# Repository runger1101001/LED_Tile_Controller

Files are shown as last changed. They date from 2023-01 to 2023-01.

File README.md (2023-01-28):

# Trixel Controller v1.0 Hardware

ESP32-C3 based controller board for trixel tiles.

Firmware for it can be found [here](https://github.com/runger1101001/led_driver_esp32).

More detailed explanation of how to use this controller can be found in the firmware documentation as well as the documentation for [the web ui](https://github.com/runger1101001/trixelcontroller-ui).

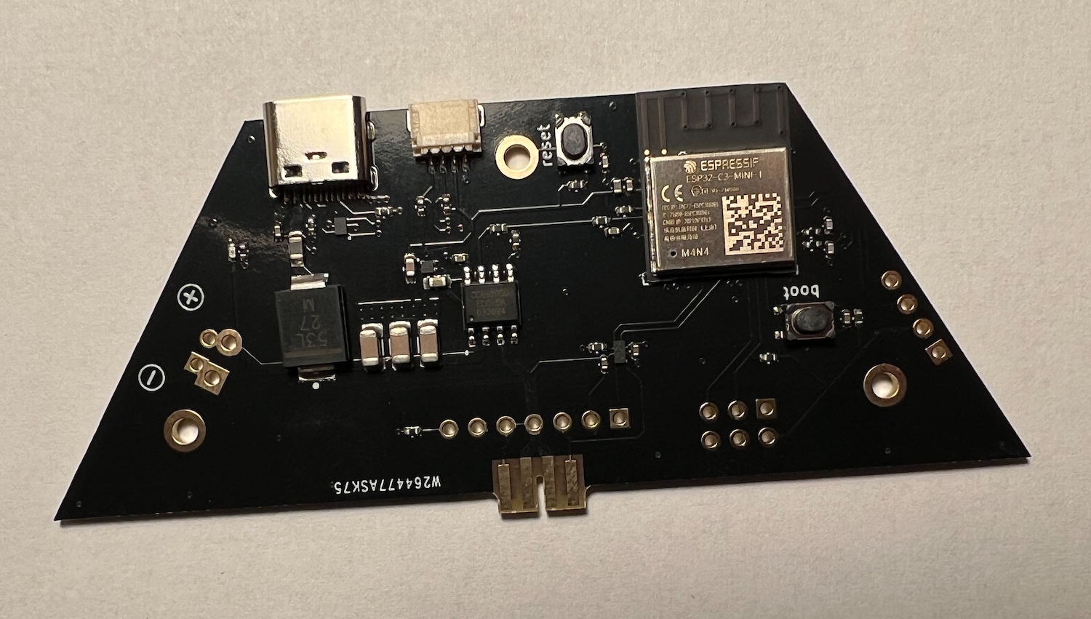
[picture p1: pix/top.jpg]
Top View


## Features

- ESP32-C3-MINI MCU
- 1 Trixel connector for board to board connections and as 1x7 header
- USB-C for power, serial debugging and programming
- Stemma/QT compatible I2C port
- Current sensing via hall effect current sensor
- Current levels up to 3A supported via USB, up to 5A via power header
- Buttons for Boot and Reset (not really needed with USB)
- Serial RX/TX routed to header for serial programming (don't know why since you have USB)
- 6 additional IOs routed to 2x3 header
- 5V power input header

## Using this project

This project was created in KiCad 6. You may need symbols/footprints from [my KiCad library](https://github.com/runger1101001/kicad-lib-runger).

Ordering the controller board PCB should not be difficult. It is a fairly simple 4 layer board. The board outline requires routing. 

Pay attention to the slot in the board to board connector (gerber layer User.1), which has to be routed out precisely for the connector to fit and work. The board thickness should be 1.6mm, other thicknesses will not work with the connector.

## Flashing the controller

To flash firmware to the controller, connect to USB via it's USB-C port. You can then program it with the usual software (ArduinoIDE, PlatformIO, etc). When configuring the software, you can treat it as a ESP32-C3-DevKit.

See the [trixel controller firmware](https://github.com/runger1101001/led_driver_esp32) for a working example using PlatformIO.

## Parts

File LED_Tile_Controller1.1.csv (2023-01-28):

Item | Ref Des | Qty | Manufacturer | Mfg Part # | Description / Value | Package | Type | Your Instructions / Notes
1 | C1,C2,C3 | 3 | Murata | GRM31CR61A476ME15K | 47uF 10V | C_1206_3216Metric | SMD | ; Unpolarized capacitor;
2 | C4,C7,C11,C14,C17,C18 | 6 | Murata | GRM155R71A104KA01J | 100nF 10V | C_0402_1005Metric | SMD | ; Unpolarized capacitor;
3 | C6 | 1 | Murata | ZRB15XR61A106ME01D | 10uF 10V | C_0402_1005Metric | SMD | ; Unpolarized capacitor;
4 | C8,C10 | 2 | Vishay | VJ0402A470GXQCW1BC | 47pF 10V | C_0402_1005Metric | SMD | ; Unpolarized capacitor;
5 | C12,C15 | 2 | Taiyo Yuden | EMK107ABJ225KA8T | 2.2uF 16V | C_0603_1608Metric | SMD | ; Unpolarized capacitor;
6 | C13 | 1 | Murata | GRT155C80J105KE01D | 1uF 6.3V | C_0402_1005Metric | SMD | ; Unpolarized capacitor;
7 | C16 | 1 | Taiyo Yuden | LMF105B7103KVHF | 10nF 10V | C_0402_1005Metric | SMD | ; Unpolarized capacitor;
8 | D2 | 1 | Vishay | SSC53L-M3/57T | SSC53L-M3/57T | D_SMC | SMD | ; Diode;
9 | D3 | 1 | Wurth | 150040VS73240 | green | LED_0402_1005Metric | SMD | ; Light emitting diode;
10 | FB1 | 1 | Laird | HI0805P390R-10 | 40Ω@100Mhz | L_0805_2012Metric | SMD | ; Ferrite bead;
11 | J5 | 1 | HRO | HRO_TYPE-C-31-M-12 | USB_C_Receptacle_USB2.0 | USB_C_Receptacle_HRO_TYPE-C-31-M-12 | SMD | ; USB 2.0-only Type-C Receptacle connector; https://www.usb.org/sites/default/files/documents/usb_type-c.zip
12 | J6 | 1 | JST | SH_SM04B-SRSS-TB | Stemma/QT | JST_SH_SM04B-SRSS-TB_1x04-1MP_P1.00mm_Horizontal | SMD | ; Generic connectable mounting pin connector, single row, 01x04, script generated (kicad-library-utils/schlib/autogen/connector/);
13 | R1,R3,R6,R7,R14,R16 | 6 | Generic | Generic 1% | 10k | R_0402_1005Metric | SMD | ; Resistor;
14 | R2,R8,R9,R10,R13 | 5 | Generic | Generic | 5k1 | R_0402_1005Metric | SMD | ; Resistor;
15 | R4,R5 | 2 | Generic | Generic | 27R | R_0402_1005Metric | SMD | ; Resistor;
16 | R11 | 1 | Generic | Generic | 330R | R_0402_1005Metric | SMD | ; Resistor;
17 | R12 | 1 | Generic | Generic | 2k2 | R_0402_1005Metric | SMD | ; Resistor;
18 | R15 | 1 | Generic | Generic 1% | 20k | R_0402_1005Metric | SMD | ; Resistor;
19 | SW1,SW2 | 2 | C&K | PTS810 SJS 250 SMTR LFS | SW_Push | PTS_810 | SMD | ; Push button switch, generic, two pins;
20 | U2 | 1 | Espressif | ESP32-C3-MINI-1-N4 | ESP32-C3-MINI-1 | ESP32-C3-MINI-1 | SMD | ; ESP32-C3-MINI-1 is a general-purpose Wi-Fi and Bluetooth LE module. This module features a rich set of peripherals and a small size, which makes it an ideal choice for smart home, industrial automation, health care, consumer electronics, etc; https://www.espressif.com/sites/default/files/documentation/esp32-c3-mini-1_datasheet_en.pdf
21 | U3 | 1 | Crosschip | CC6900SO-5A | CC6900SO-5A | SOIC-8_3.9x4.9mm_P1.27mm | SMD | ; ±20A Bidirectional Hall-Effect Current Sensor, +3.3V supply, 66mV/A, SOIC-8; http://www.allegromicro.com/~/media/Files/Datasheets/ACS725-Datasheet.ashx?la=en
22 | U4 | 1 | Micrel / Microchip | MIC5524-3.3YMT-T5 | MIC5524-3.3YMT-T5 | TDFN-4-1EP_1x1mm_P0.65mm_EP0.5x0.5mm | SMD | ; 500mA low dropout LDO, Fixed or Adjustable, 1x1mm Thin-DFN; https://www.mouser.at/datasheet/2/268/MIC5524-875860.pdf
23 | U5 | 1 | Nexperia | PRTR5V0U2F | PRTR5V0U2F | SOT-886 | SMD | ; Very low capacitance ESD protection diode, 2 data-line, SOT-666; https://www.st.com/resource/en/datasheet/usblc6-2.pdf
24 | U6 | 1 | NXP | NXB0102GTX | NXB0102GTX | SOT833-1 (XSON8) | SMD | ; Dual supply translating transceiver; auto direction sensing; 3-state; https://www.mouser.at/datasheet/2/916/NXB0102-1714053.pdf

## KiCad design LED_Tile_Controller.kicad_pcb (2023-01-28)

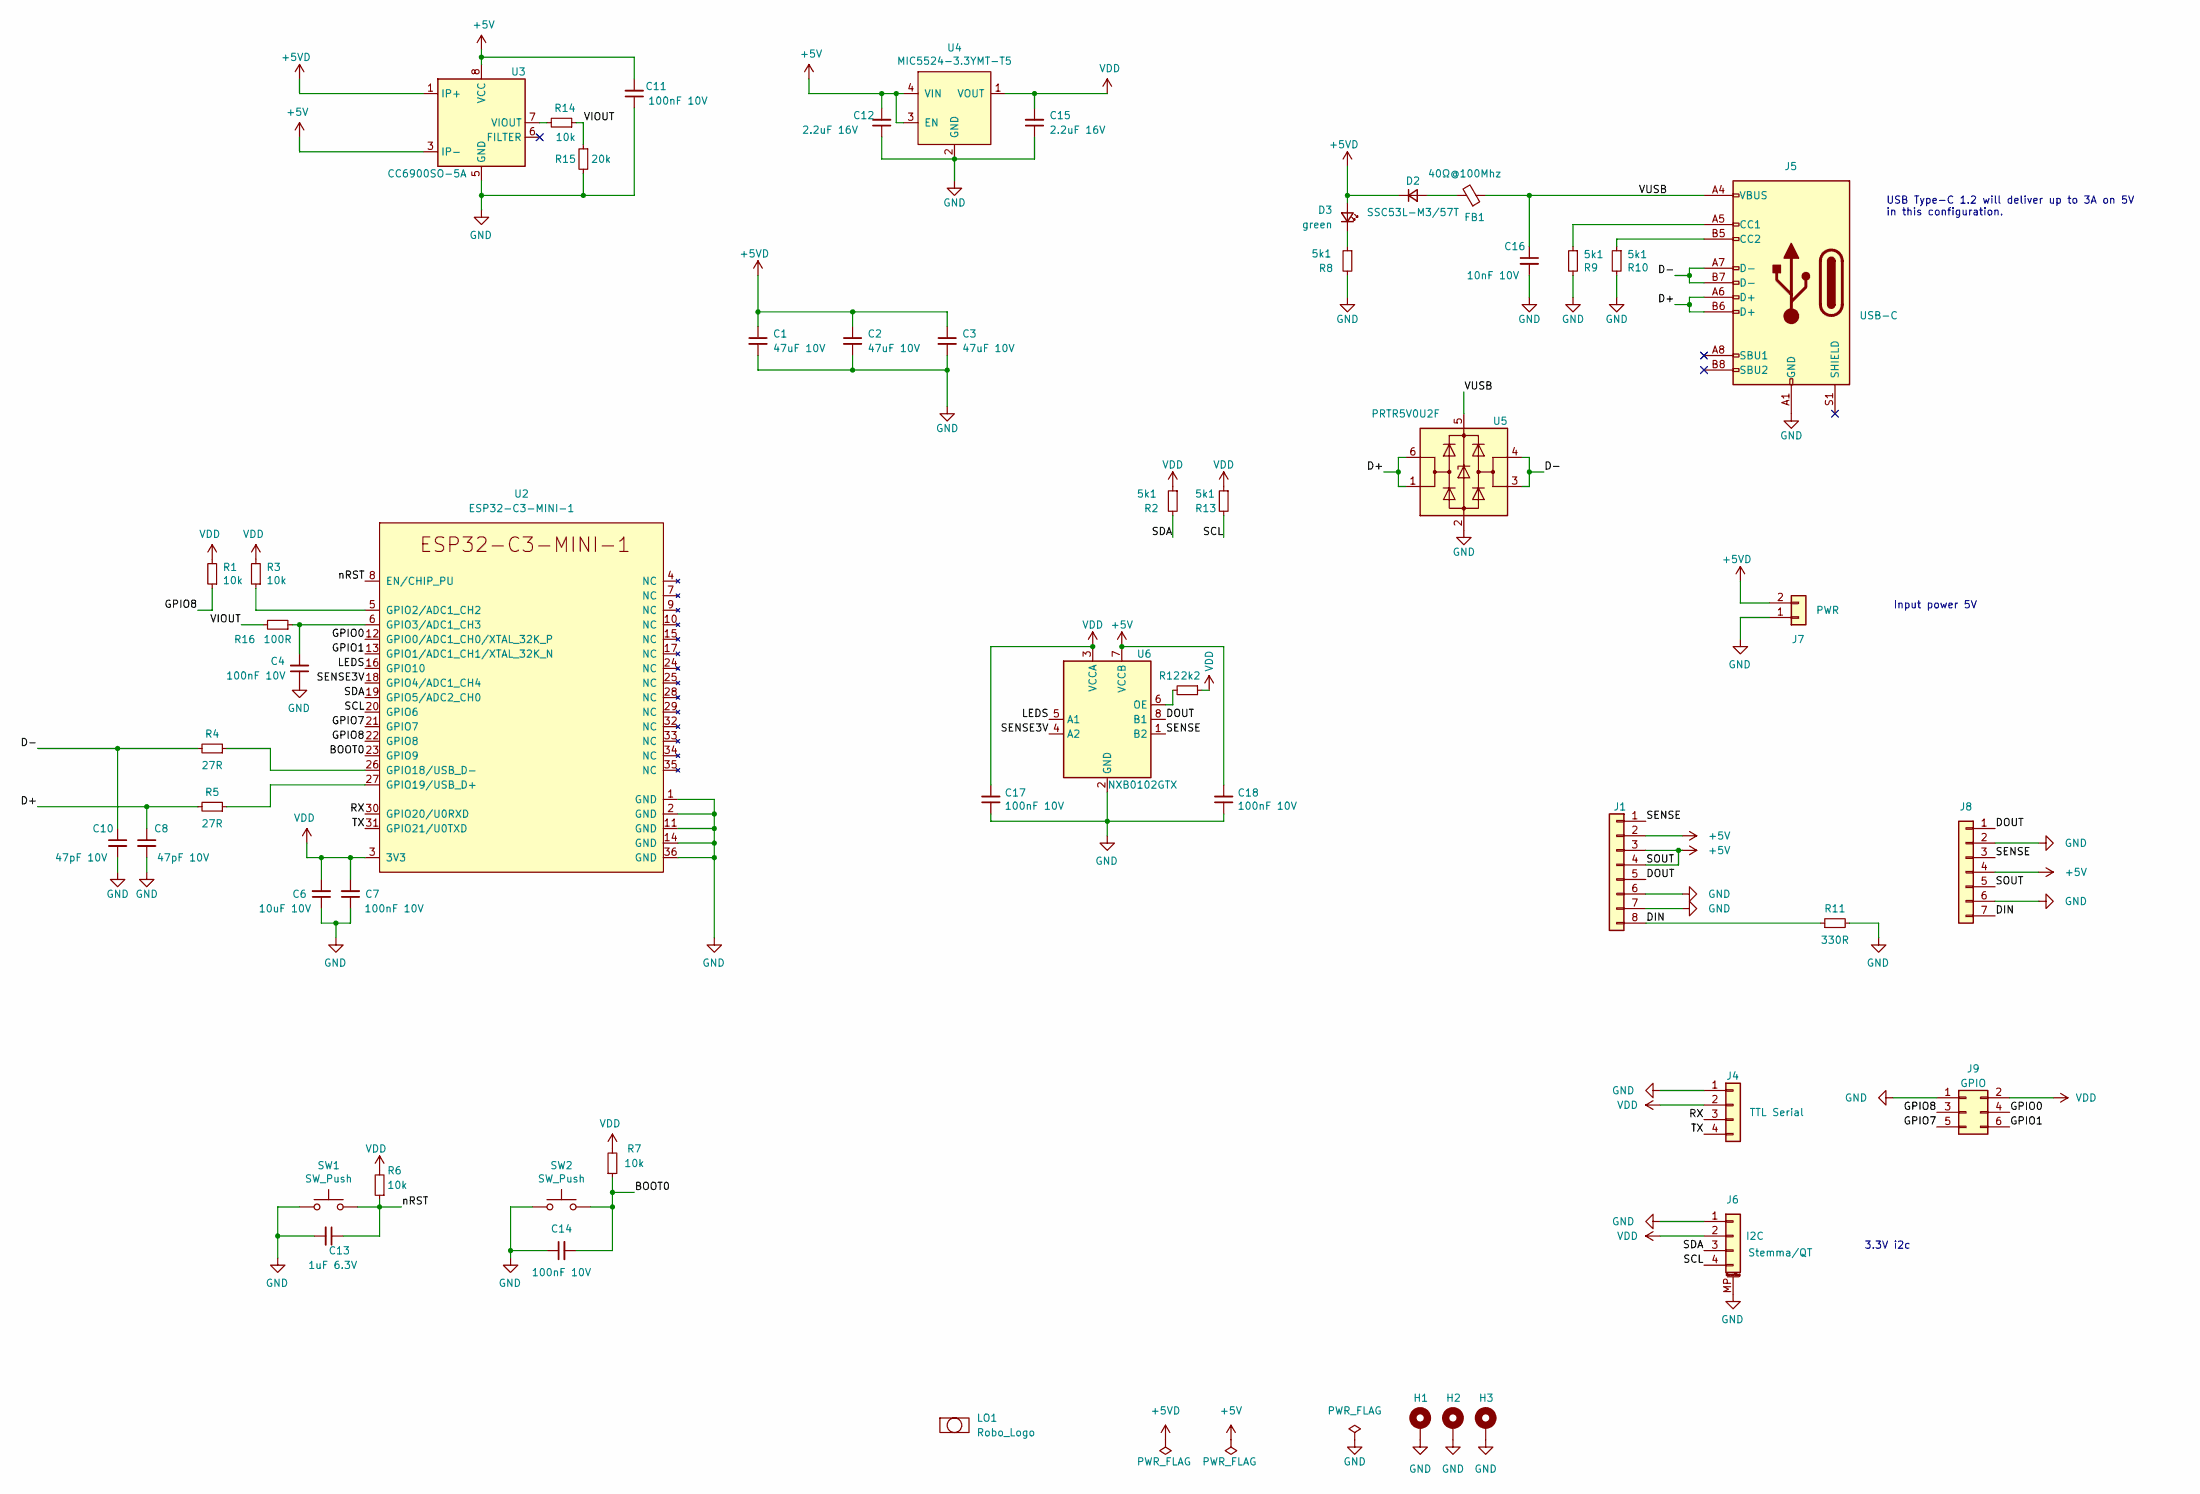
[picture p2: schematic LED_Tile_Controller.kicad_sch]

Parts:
C1, C2, C3: 47uF 10V; C_1206_3216Metric; Part GRM31CR61A476ME15K
C4, C7, C11, C14, C17, C18: 100nF 10V; C_0402_1005Metric; Part GRM155R71A104KA01J
C6: 10uF 10V; C_0402_1005Metric; Part ZRB15XR61A106ME01D
C8, C10: 47pF 10V; C_0402_1005Metric; Part VJ0402A470GXQCW1BC
C12, C15: 2.2uF 16V; C_0603_1608Metric; Part EMK107ABJ225KA8T
C13: 1uF 6.3V; C_0402_1005Metric; Part GRT155C80J105KE01D
C16: 10nF 10V; C_0402_1005Metric; Part LMF105B7103KVHF
D2: SSC53L-M3/57T; D_SMC; Part SSC53L-M3/57T
D3: green; LED_0402_1005Metric; Part 150040VS73240
FB1: 40Ω@100Mhz; L_0805_2012Metric; Part HI0805P390R-10
H1, H2, H3: MountingHole_Pad; MountingHole_2.2mm_M2_DIN965_Pad
J1: AVX 009159008061816; AVX_Edge_8; Part 009159008061816
J4: Conn_01x04; PinHeader_1x04_P2.54mm_Vertical
J5: USB_C_Receptacle_USB2.0; USB_C_Receptacle_HRO_TYPE-C-31-M-12; Part HRO_TYPE-C-31-M-12
J6: Stemma/QT; JST_SH_SM04B-SRSS-TB_1x04-1MP_P1.00mm_Horizontal; Part SH_SM04B-SRSS-TB
J7: Conn_01x02; Power_Combo
J8: Conn_01x07; PinHeader_1x07_P2.54mm_Horizontal
J9: Conn_02x03_Odd_Even; PinHeader_2x03_P2.54mm_Vertical
LO1: Robo_Logo; Robo_logo2
R1, R3, R6, R7: 10k; R_0402_1005Metric; Part Generic
R2, R13: 5k1; R_0402_1005Metric; Part Generic
R4, R5: 27R; R_0402_1005Metric; Part Generic
R8, R9, R10: 5k1; R_0402_1005Metric; Part Generic 1%
R11: 330R; R_0402_1005Metric; Part Generic
R12: 2k2; R_0402_1005Metric; Part Generic
R14: 10k; R_0402_1005Metric; Part Generic 1%
R15: 20k; R_0402_1005Metric; Part Generic 1%
R16: 100R; R_0402_1005Metric; Part Generic 1%
SW1, SW2: SW_Push; PTS_810; Part PTS810 SJS 250 SMTR LFS
U2: ESP32-C3-MINI-1; Part ESP32-C3-MINI-1-N4
U3: CC6900SO-5A; SOIC-8_3.9x4.9mm_P1.27mm; Part CC6900SO-5A
U4: MIC5524-3.3YMT-T5; TDFN-4-1EP_1x1mm_P0.65mm_EP0.5x0.5mm; Part MIC5524-3.3YMT-T5
U5: PRTR5V0U2F; SOT-886; Part PRTR5V0U2F
U6: NXB0102GTX; SOT833-1 (XSON8); Part NXB0102GTX

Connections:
+5V: C11.2, C12.2, C18.2, J1.2, J1.3, J1.4, J8.4, J8.5, U3.3 (IP-), U3.4 (IP-), U3.8 (VCC), U4.3 (EN), U4.4 (VIN), U6.7 (VCCB)
+5VD: C1.1, C2.1, C3.1, D2.1 (K), D3.2 (A), J7.2, U3.1 (IP+), U3.2 (IP+)
/BOOT0: C14.2, R7.1, SW2.2, U2.23 (GPIO9)
/D+: C8.1, J5.A6 (D+), J5.B6 (D+), R5.2, U5.1 (I/O1), U5.6 (I/O1)
/D-: C10.1, J5.A7 (D-), J5.B7 (D-), R4.2, U5.3 (I/O2), U5.4 (I/O2)
/DIN: J1.8, J8.7, R11.1
/DOUT: J1.5, J8.1, U6.8 (B1)
/GPIO0: J9.4, U2.12 (GPIO0/ADC1_CH0/XTAL_32K_P)
/GPIO1: J9.6, U2.13 (GPIO1/ADC1_CH1/XTAL_32K_N)
/GPIO7: J9.5, U2.21 (GPIO7)
/GPIO8: J9.3, R1.1, U2.22 (GPIO8)
/LEDS: U2.16 (GPIO10), U6.5 (A1)
/RX: J4.3, U2.30 (GPIO20/U0RXD)
/SCL: J6.4, R13.2, U2.20 (GPIO6)
/SDA: J6.3, R2.2, U2.19 (GPIO5/ADC2_CH0)
/SENSE: J1.1, J8.3, U6.1 (B2)
/SENSE3V: U2.18 (GPIO4/ADC1_CH4), U6.4 (A2)
/TX: J4.4, U2.31 (GPIO21/U0TXD)
/VIOUT: R14.1, R15.1, R16.2
/VUSB: C16.1, FB1.1, J5.A4 (VBUS), J5.A9 (VBUS), J5.B4 (VBUS), J5.B9 (VBUS), U5.5 (VBUS)
/nRST: C13.1, R6.1, SW1.2, U2.8 (EN/CHIP_PU)
GND: C1.2, C2.2, C3.2, C4.1, C6.1, C7.1, C8.2, C10.2, C11.1, C12.1, C13.2, C14.1, C15.1, C16.2, C17.1, C18.1, H1.1, H2.1, H3.1, J1.6, J1.7, J4.1, J5.A1 (GND), J5.A12 (GND), J5.B1 (GND), J5.B12 (GND), J6.1, J6.MP (MountPin), J7.1, J8.2, J8.6, J9.1, R8.2, R9.2, R10.2, R11.2, R15.2, SW1.1, SW2.1, U2.1 (GND), U2.2 (GND), U2.11 (GND), U2.14 (GND), U2.36 (GND), U3.5 (GND), U4.2 (GND), U4.5 (GND), U5.2 (GND), U6.2 (GND)
unnamed: C4.2, R16.1, U2.6 (GPIO3/ADC1_CH3)
unnamed: D2.2 (A), FB1.2
unnamed: D3.1 (K), R8.1
unnamed: J5.A5 (CC1), R9.1
unnamed: J5.B5 (CC2), R10.1
unnamed: R3.1, U2.5 (GPIO2/ADC1_CH2)
unnamed: R4.1, U2.26 (GPIO18/USB_D-)
unnamed: R5.1, U2.27 (GPIO19/USB_D+)
unnamed: R12.2, U6.6 (OE)
unnamed: R14.2, U3.7 (VIOUT)
VDD: C6.2, C7.2, C15.2, C17.2, J4.2, J6.2, J9.2, R1.2, R2.1, R3.2, R6.2, R7.2, R12.1, R13.1, U2.3 (3V3), U4.1 (VOUT), U6.3 (VCCA)

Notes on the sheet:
3.3V i2c
USB Type-C 1.2 will deliver up to 3A on 5V in this configuration.
Input power 5V

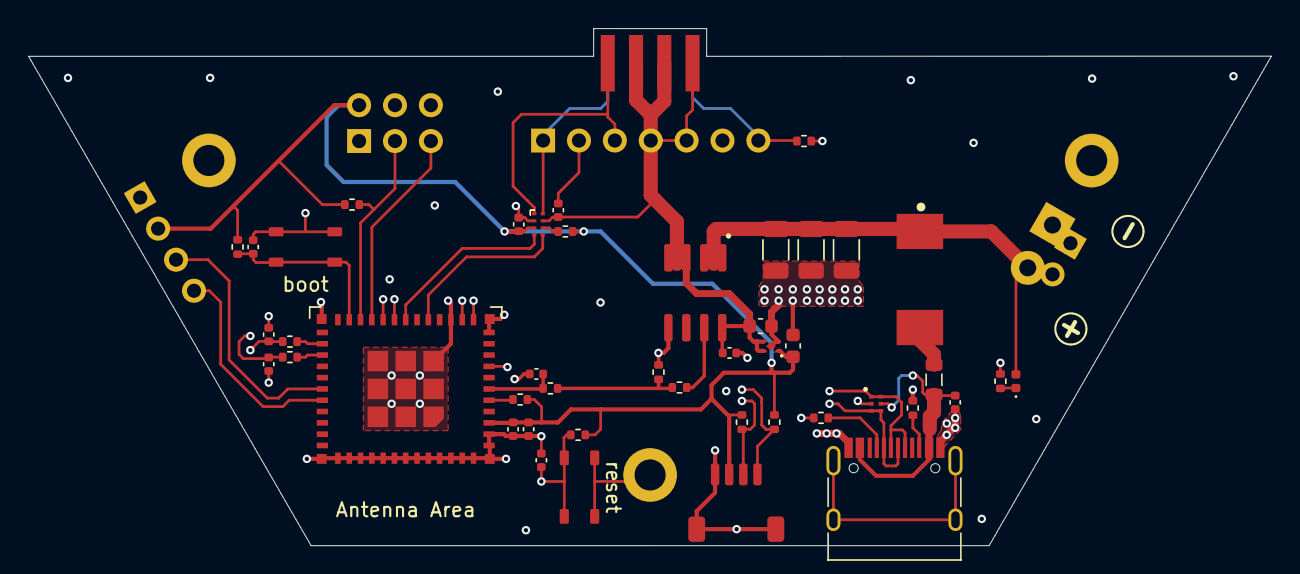
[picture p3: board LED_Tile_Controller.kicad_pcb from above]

Board: 4 copper layers, 88.0 x 36.6 mm, 53 parts (1 on the bottom side), 33 nets.

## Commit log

2022-12-11 first import of LED tile controller
    [Buck_XL4015.kicad_sch, LED_Tile_Controller.csv, LED_Tile_Controller.kicad_pcb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]
2023-01-28 led tile controller working nicely :-)
    [LED_Tile_Controller.csv, LED_Tile_Controller.kicad_pcb, LED_Tile_Controller.kicad_sch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]
2023-01-28 added note on board thickness to readme

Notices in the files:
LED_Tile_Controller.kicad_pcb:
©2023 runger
